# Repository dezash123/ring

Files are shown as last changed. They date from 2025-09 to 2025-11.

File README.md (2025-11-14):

## comparison

| ring | width | thickness | sizes | price |
| --- | --- | --- | --- | --- |
| mine | 7.0-7.6 | 2.4 | 5.5-infinite | ~$50 |
| [circular](https://shop.circular.xyz/products/circular-ring-2) | 7.8 | 2.55 | 6-14 | $349 |
| [oura](https://ouraring.com/store/rings/oura-ring-4) | 7.9 | 2.88 | 4-15 | ($499 or $349) + $6/mo |
| [galaxy ring](https://www.samsung.com/us/rings/galaxy-ring/) | 7.0 | 2.6 | 5-13 | $399 |
| [ultrahuman](https://www.ultrahuman.com/ring/buy/us/) | 8.1 | 2.45-2.8  | unclear | $349 |

6.9mm width can be made by inserting electronics mid-print
## pricing calculation
- jlcpcb: $186.59 for 2 assembled
	- board: $0.40
	- components: $26.38
	- SMT (per unit): $0.86
	- inspection: $3.14
	- everything else is fixed costs
- battery: $3.50
- casing: $0.08

total: $34.36
## features
- bq27427: battery monitor
- max30102: spo2 + heart rate
- lsm6dsox: accelerometer + gyro; provides step counter + gesture detection
- tmp117: skin temperature sensor
- im72d128v01: mic, higher-quality than most smartphones
- 17 mah battery

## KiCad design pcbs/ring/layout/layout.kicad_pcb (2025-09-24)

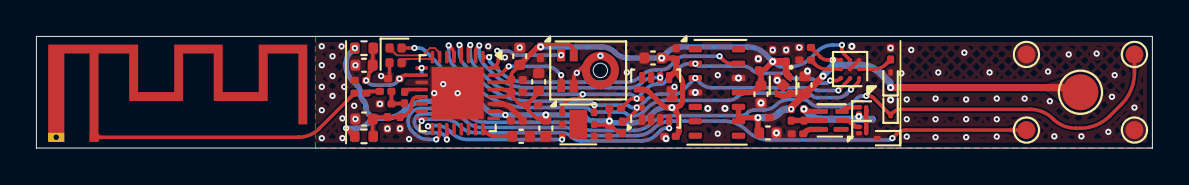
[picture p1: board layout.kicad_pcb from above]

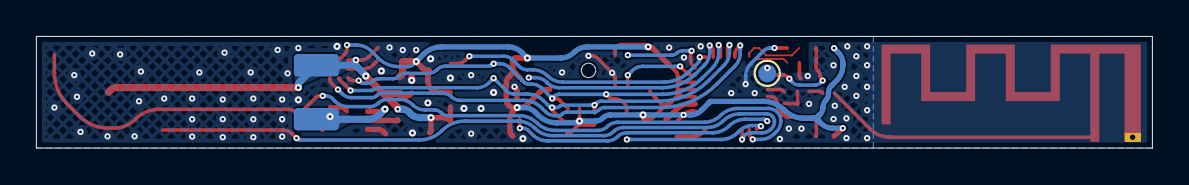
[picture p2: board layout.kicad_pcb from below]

Board: 2 copper layers, 62.0 x 6.2 mm, 62 parts (2 on the bottom side), 33 nets.

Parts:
C1, C30, C31: 1uF; C_0201_0603Metric
C2: 2.2uF; C_0201_0603Metric
C3, C6, C7, C11, C15, C18, C21, C23, C24, C25, C27, C28: 100nF; C_0201_0603Metric
C4, C8, C10, C16, C19, C26, C29: 1uF; C_0402_1005Metric
C5, C20: 10uF; C_0402_1005Metric
C9: 10nF; C_0201_0603Metric
C12: 1.6pF; C_0201_0603Metric
C13: 18pF; C_0201_0603Metric
C14, C17: 120pF; C_0201_0603Metric
C22: 4.7uF; C_0402_1005Metric
FB1, FB2: 0 0Hz; R_0402_1005Metric
L1: 2nH; L_0201_0603Metric
L2: 3.200000000000001nH; L_0201_0603Metric
R1, R2: 4.7k; R_0201_0603Metric
R3: 10k; R_0201_0603Metric
R4: 2.2k; R_0201_0603Metric
R5: 330; R_0201_0603Metric
TP1, TP3, TP4, TP5, TP6: TestPoint_Pad_D1.0mm
TP2: TestPoint_Pad_D2.0mm
U1: ?; BGA-9_1.6x1.6mm_Layout3x3_P0.5mm
U2: ?; Battery
U3, U4: ?; Texas_PicoStar_DFN-3_0.69x0.60mm
U5: ?; WSON-6_1.5x1.5mm_P0.5mm
U6: ?; QFN-32-1EP_4x4mm_P0.4mm_EP2.9x2.9mm
U7: ?; Texas_SWRA117D_2.4GHz_Right
U8: ?; Maxim_OLGA-14_3.3x5.6mm_P0.8mm
U9: ?; LGA-14_3x2.5mm_P0.5mm_LayoutBorder3x4y
U10: ?; Infineon_PG-LLGA-5-1
U11, U12, U13: ?; D_SOD-923
U14: ?; WSON-6-1EP_2x2mm_P0.65mm_EP1x1.6mm
U15: ?; Texas_X2SON-4_1x1mm_P0.65mm
Y1: 38.4MHz; Crystal_SMD_1210-4Pin_1.2x1.0mm

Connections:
GND: C1.2, C2.2, C4.2, C5.2, C6.2, C7.2, C8.2, C9.2, C10.2, C11.2, C12.2, C14.2, C15.2, C16.2, C17.2, C18.2, C19.2, C20.2, C21.2, C22.2, C23.2, C24.2, C25.2, C26.2, C27.2, C28.2, C29.2, C30.2, C31.2, R3.2, R4.2, TP5.1, TP6.1, U1.B2, U1.C1, U4.2, U6.11, U6.27, U6.33, U7.2, U8.4, U8.12, U9.1, U9.2, U9.3, U9.6, U9.7, U10.4, U10.5, U11.2, U12.2, U13.2, U14.2, U14.4, U15.2, U15.5, Y1.2, Y1.4
VBATT: C1.1, C20.1, C21.1, C29.1, R5.1, TP2.1, U1.C3, U2.1, U8.9, U8.10, U11.1, U15.3, U15.4
VDD: C5.1, C6.1, C7.1, C8.1, C9.1, C10.1, C11.1, C22.1, C23.1, C24.1, C25.1, C26.1, C27.1, C28.1, C30.1, C31.1, FB1.1, FB2.1, R1.1, R2.1, U1.C2, U6.26, U6.28, U6.29, U6.30, U8.11, U9.5, U9.8, U9.12, U10.2, U14.5, U15.1
bat_low: U1.A1, U6.5
batman.batman_vdd_out: C2.1, U1.B3
batman.bin: R3.1, U1.B1
battery.bat2: C3.1, R5.2, U5.5
battery.bat_cout: U4.1, U5.2
battery.bat_dout: U3.1, U5.3
battery.bat_qm: U3.3, U4.3
battery.bat_vm: R4.1, U5.6
battery.bat_vss: C3.2, U2.2, U3.2, U5.4
cpu.ant: L1.1, U6.12
cpu.ant.out1: C12.1, L1.2, L2.1
cpu.ant.out2: C13.1, L2.2
cpu.ant.out3: C13.2, U7.1
cpu.decouple: C4.1, U6.24
cpu.pavdd: C14.1, C15.1, C16.1, FB1.2, U6.13
cpu.rfvdd: C17.1, C18.1, C19.1, FB2.2, U6.10
cpu.xin: U6.7, Y1.1
cpu.xout: U6.8, Y1.3
hbt.NC: U8.1, U8.5, U8.6, U8.7, U8.8, U8.14
hbt_int: U6.1, U8.13
imu_int1: U6.16, U9.4
imu_int2: U6.2, U9.9
mic_clk: U6.31, U10.3
mic_data: U6.32, U10.1
rst: TP1.1, U6.9
scl: R2.2, U1.A3, U6.3, U8.2, U9.13, U14.1
sda: R1.2, U1.A2, U6.4, U8.3, U9.14, U14.6
swclk: TP4.1, U6.18, U13.1
swdio: TP3.1, U6.19, U12.1
tmp_int: U6.17, U14.3

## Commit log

2025-09-24 moved antenna and drc fully passes
    [layout.kicad_pcb]
2025-09-24 remove non-zener version
    [ring.kicad_pcb, ring.kicad_sch]
2025-09-24 pcb fully fully done
    [layout.kicad_pcb]
